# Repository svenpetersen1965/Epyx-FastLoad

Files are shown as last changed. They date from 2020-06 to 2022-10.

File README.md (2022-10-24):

# Epyx-FastLoad
A rebuild of the Epyx Fast Load cartridge for the Commodore C64 in the same format like the <a href="https://github.com/bwack/Versa64Cart">Versa64Cart<a>,
The dimensions are the same and the location of the reset switch is the same.

The software and the user manual can be obtained from this website: <a href="https://rr.pokefinder.org/wiki/Epyx_FastLoad">Epyx FastLoad (pokefinder)</a>  

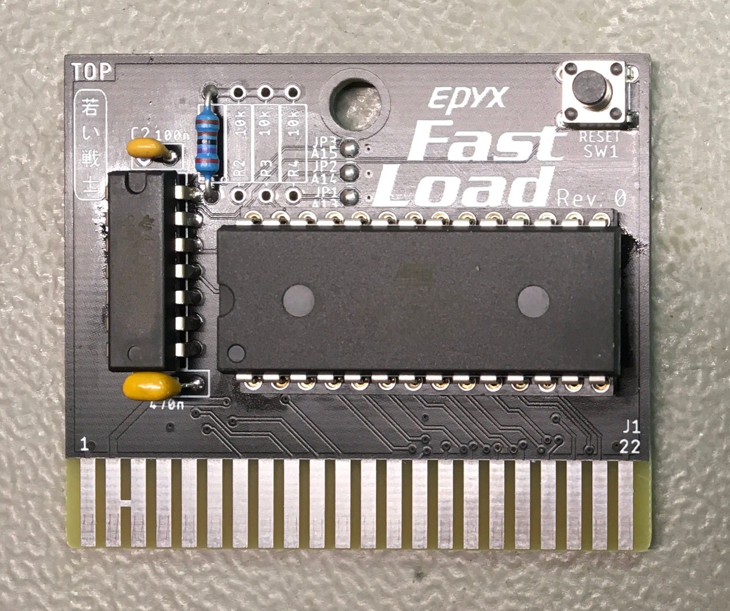
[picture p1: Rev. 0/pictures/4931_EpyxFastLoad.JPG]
Epyx FastLoad


# BOM value
The bom value is 8€, which includes the M27C512 EPROM. It was calculated with domestic prices. 

# Rev. 1
There is a jumper for selecting the software versions (there is obviously more than one version).
  
# Rev. 2
Rev. 2 is only a mechanical revision. Notches for tfw8bit.com Stumpy cartridge case were added. 

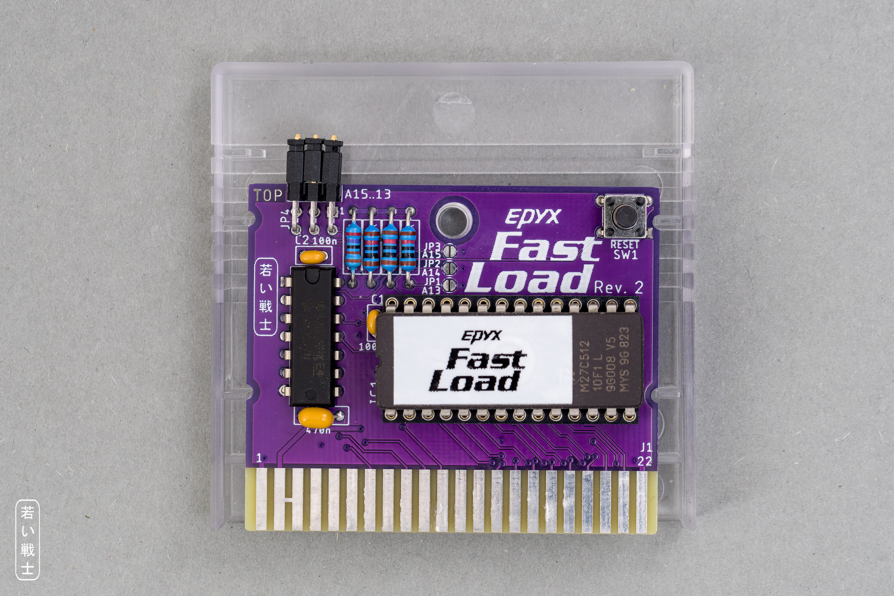
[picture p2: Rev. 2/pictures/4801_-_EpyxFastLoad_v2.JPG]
Epyx FastLoad v2

  
There is a version of the Gerber files and the eagle file without a documentation frame, since some PCB manufacturer's websites have a problem with it.

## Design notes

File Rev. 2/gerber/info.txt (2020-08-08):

      
       Board: EpyxFastLoad
       Rev.:  1
  
       Files:
       ======
  
       All Gerber files are generated in extended gerber format (RS274X)
       *.TOP        : Film top copper
       *.BOT        :  -"- bottom copper
       *.STC        :  -"- top soldermask 
       *.STS        :  -"- bottom soldermask
       *.PLC        :  -"- silk screen top
       *.PLS        :  -"- silk screen bottom
       *.DK         : Drills plated Through (Excellon)
       *.NDK        : Drills not plated Through (Excellon)
       *.OUT        : Board outline

       Board Size:
       ===========
       Length     :   58.0 mm
       Width      :   48.9 mm
       Thickness  :   1.6 mm
       Material   :   FR 4
       Copper     :   35 um
       Surface    :   HASL
       
       Remarks:
       ========
       minimum drill: 0.35mm
       minimum width: 8 mil
       minimum distance: 6 mil

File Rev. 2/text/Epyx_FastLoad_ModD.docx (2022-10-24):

Epyx FastLoad Cartridge for the C64 Rev. 2

Module Description

This is a cartridge PCB, which is suitable for the Epyx FastLoad software.

This software can be obtained here: https://rr.pokefinder.org/wiki/Epyx_FastLoad

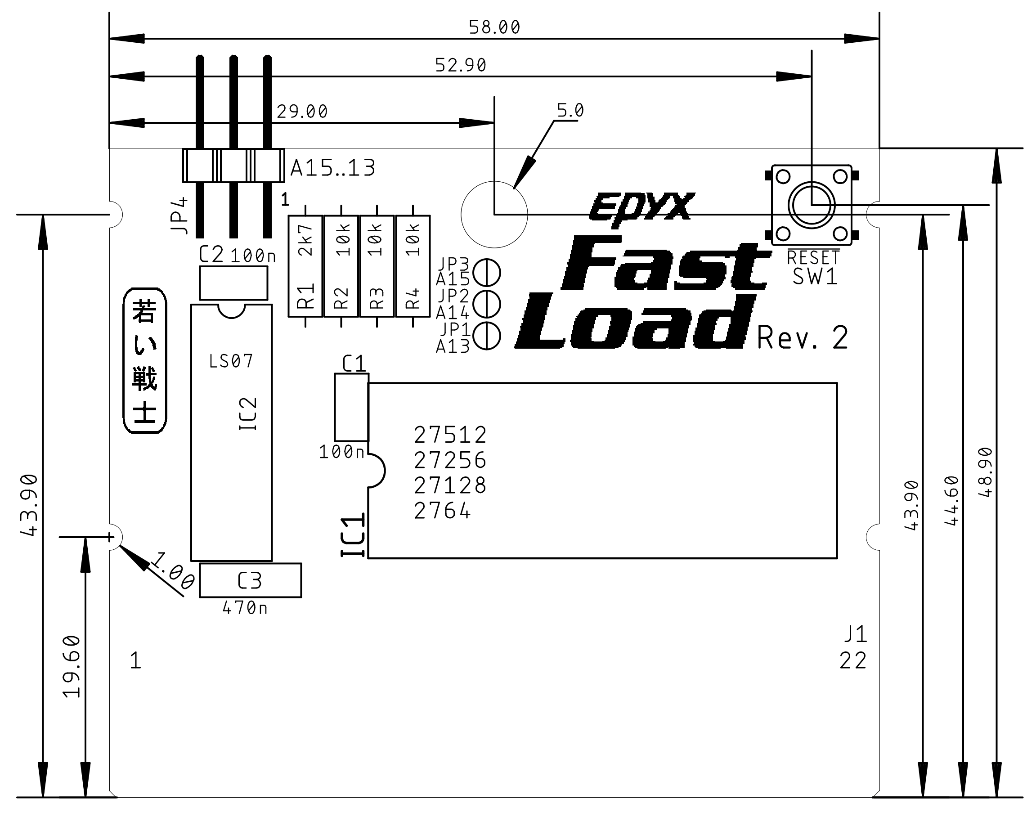
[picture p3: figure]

Figure 1: Dimensions

The circuit is based on a schematic found at the source, which was mentioned before.

A RESET button was added to this circuit and solder bridges (JP1 to JP3) for configuring the cartridge for being used with 27C64, 27C128, 27C256 and 27C512 EPROMs for a greater part availability.

EPROM | Jumper
| JP3 = A15 | JP2 = A14 | JP1 = A13
27C64 | open | open | open
27C128 | open | open | close
27C256 | open | close | close
27C512 | close | close | close

The software is programmed to the EPROM offset address 0x0000 (hex).

The dimensions are equal to the dimensions of the Versa64Cart. Notches for the Stumpy Cartridge Case were added in Rev. 2.

The memory slot can be selected with a jumper (JP4). Leave JP1..3 open and set the jumpers on the pins accordingly.

# Revision History

## Rev. 0

- Prototype, fully functional

## Rev. 1

- Board Revision
- Added JP4

## Rev. 2

- Notches added for fitting the tfw8bit.com Stumpy Cartridge Case (https://www.thefuturewas8bit.com/shop/commodore/c64/c64romcart.html)

Epyx_FastLoad_ModD.docx 24.10.2022 15:57 Drafted by Sven Petersen Page 2 of 2 Doc.-No.: 146-6-01-02

Epyx_FastLoad_ModD.docx 24.10.2022 15:57 Drafted by Sven Petersen Page 1 of 1 Doc.-No.: 000-6-00-00

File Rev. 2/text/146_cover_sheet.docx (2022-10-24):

Project Documentation

Epyx FastLoad Cartridge for the C64

Project number: 146

Revision: 2

Date: 24.10.2022

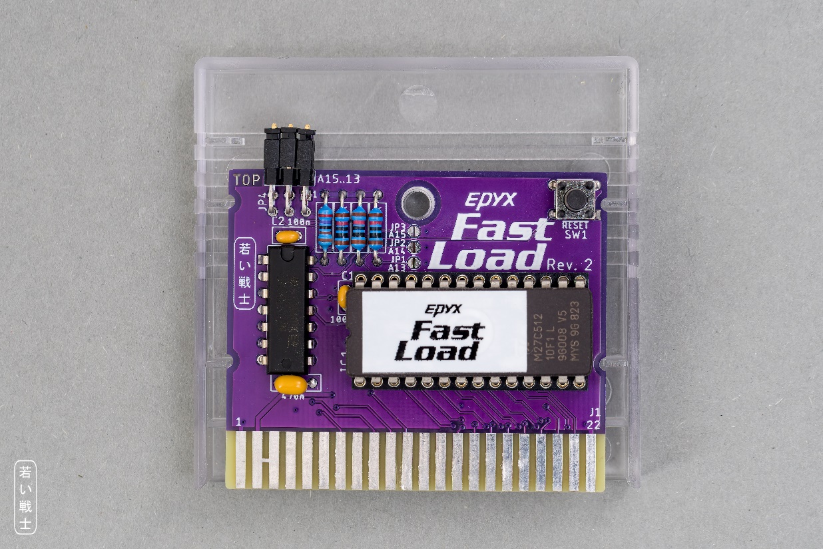
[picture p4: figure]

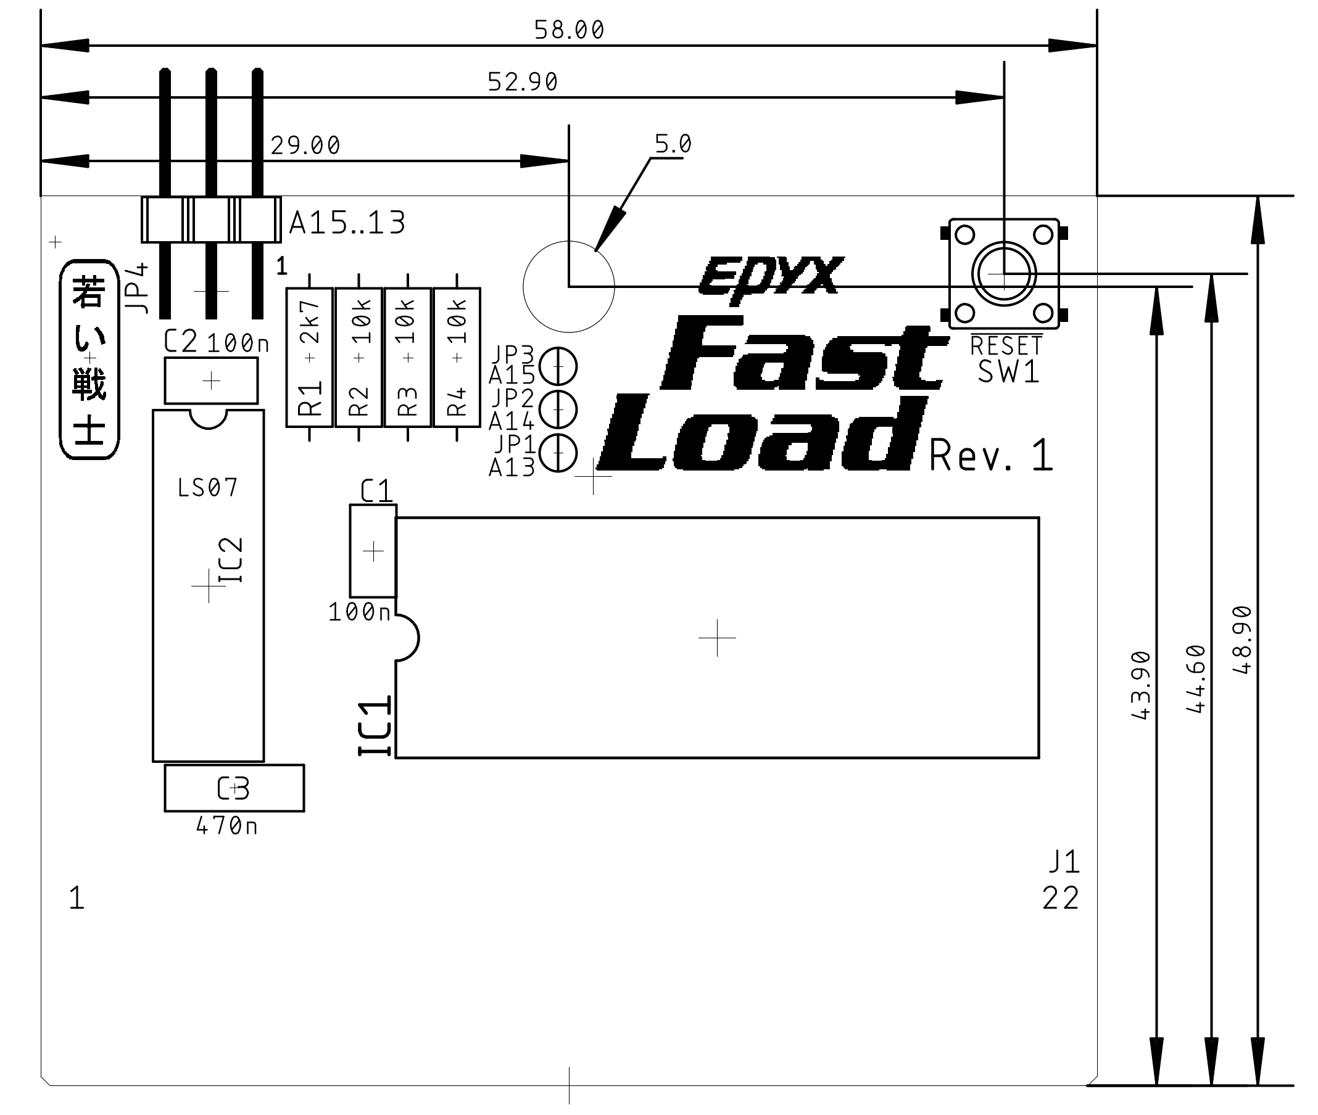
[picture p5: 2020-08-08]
Rev. 1/pictures/dimensions.png

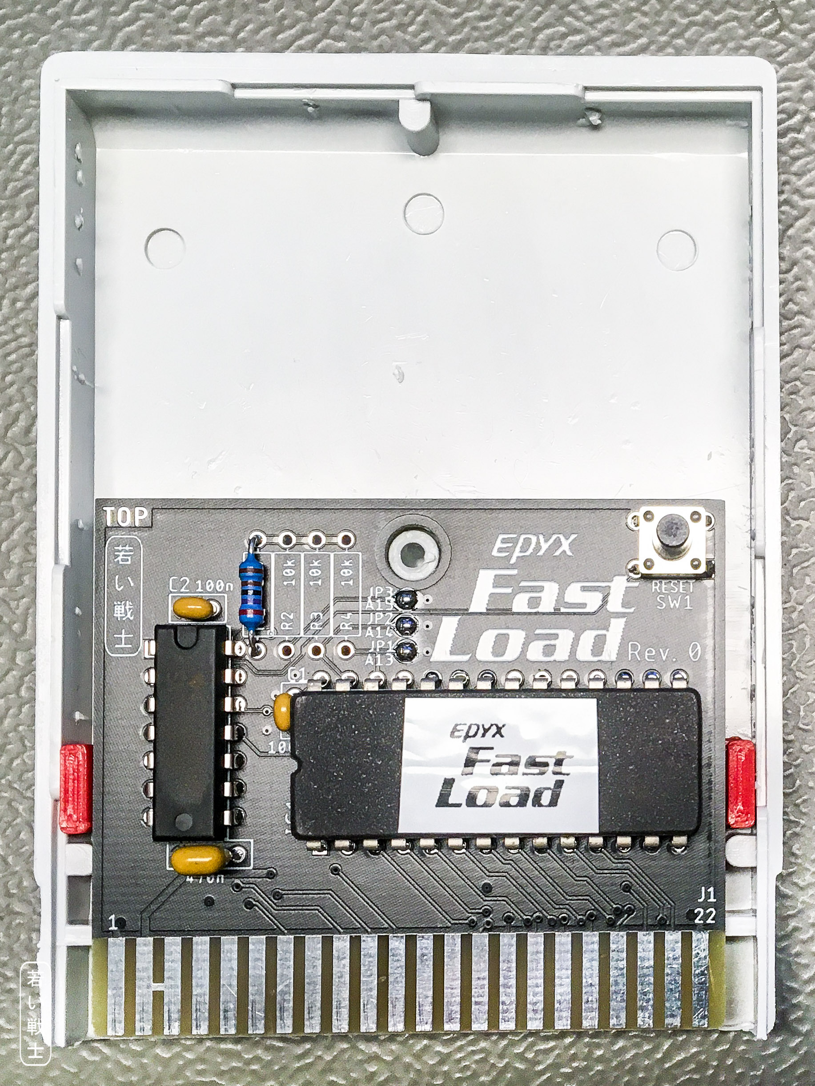
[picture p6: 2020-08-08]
Rev. 1/pictures/5124_EpyxFastLoad.JPG

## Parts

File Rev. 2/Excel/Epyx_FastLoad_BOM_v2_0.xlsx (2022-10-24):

Epxy FastLoad Cartridge Rev. 2
Bill of Material Rev. 2.0
Pos. | Qty | Value | Footprint | Ref.-No. | Comment
1 | 1 | 146-2-01-02 | 2 Layer | PCB Rev. 2 | 2 layer, Cu 35µ, HASL, 58.0mm x 48.9mm, 1.6mm FR4
2 | 3 | not an actual part | CP_OP | JP1, JP2, JP3 | Solder bridge. Configure according to doc. no. 146-6-01-**
3 | 2 | 100n | C-2,5 | C1, C2 | ceramic capacitor, pitch 2.54mm
4 | 3 | 10k | R-10 | R2, R3, R4 | resistor, metal film, 0.6W, 10% or better
5 | 1 | 27C512 | DIL28-6 | IC1 | EPROM. Alternative: 27C64, 27C128, 27C256
6 | 1 | 2k7 | R-10 | R1 | resistor, metal film, 0.6W, 10% or better
7 | 1 | 470n | C-5 | C3 | ceramic capacitor, pitch 5.08mm
8 | 1 | JTP-1130 | JTP-1130 | SW1 | tact switch, 6x6mm,
9 | 1 | SN74LS07N | DIL-14 | IC2 | e.g. Texas Instruments SN74LS07N
10 | 1 | Pin header, 2x3, 90° | 2x3, 90° | JP4 | Optional Pinherader
11 | 3 | Jumper 2.54mm |  | (JP4) | Optional Jumper
 |  | Rev. History
 |  | Rev. 1
Pos. | 1 | Board revision
Pos. | 10 | new
Pos. | 11 | new
 |  | Rev. 2
Pos. | 1 | Board revision

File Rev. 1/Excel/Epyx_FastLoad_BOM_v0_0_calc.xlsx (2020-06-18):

Epxy FastLoad Cartridge Rev. 0
Bill of Material Rev. 0.0
Pos. | Qty | Value | €/ea | € | Comment
1 | 1 | 146-2-01-00 | 1.00 € | 1.00 € | 2 layer, Cu 35µ, HASL, 58.0mm x 48.9mm, 1.6mm FR4
2 | 3 | not an actual part | 0.00 € | 0.00 € | Solder bridge. Configure according to doc. no. 146-6-01-**
3 | 2 | 100n | 0.20 € | 0.40 € | ceramic capacitor, pitch 2.54mm
4 | 3 | 10k | 0.05 € | 0.15 € | resistor, metal film, 0.6W, 10% or better
5 | 1 | 27C512 | 5.40 € | 5.40 € | EPROM. Alternative: 27C64, 27C128, 27C256
6 | 1 | 2k7 | 0.05 € | 0.05 € | resistor, metal film, 0.6W, 10% or better
7 | 1 | 470n | 0.19 € | 0.19 € | ceramic capacitor, pitch 5.08mm
8 | 1 | JTP-1130 | 0.15 € | 0.15 € | tact switch, 6x6mm,
9 | 1 | SN74LS07N | 0.66 € | 0.66 € | e.g. Texas Instruments SN74LS07N
10 |  |  | Total | 8.00 €

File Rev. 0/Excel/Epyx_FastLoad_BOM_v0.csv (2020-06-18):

Qty | Value | Device | Package | Parts | Description
3 |  | OPEN | CP_OP | JP1, JP2, JP3 | open Cutpad
2 | 100n | CAP01 | C-2,5 | C1, C2
3 | 10k | RES04 | R-10 | R2, R3, R4
1 | 27C512-DIP28 | M27C512-DIP28 | DIL28-6 | IC1
1 | 2k7 | RES04 | R-10 | R1
1 | 470n | CAP02 | C-5 | C3
1 | C64-EXPANSION-PORT | C64-EXPANSIONPNARROW | EXPANSIO_SQ | J1
1 | JTP-1130 | JTP-1130 | JTP-1130 | SW1
1 | SN74LS07N | 7407N | DIL-14 | IC2

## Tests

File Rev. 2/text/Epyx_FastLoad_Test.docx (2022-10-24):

Epyx FastLoad Cartridge for the C64 Rev. 2

Testing

# Tests

The tests were carried out with the prototype Rev. 0 and Rev. 2. The software was stored on an AT27C256R (Atmel) and an ST M27C512 EPROM.

The Epxy FastLoad cartridge was tested with:

- ASSY 250469
- ASSY 250425
- ASSY 250407
- Ultimate 64 Elite (Firmware v1.26)

The Ultimate 64 Elite did not boot. This is a known issue. This was not tested with Rev. 2 again.

All original C64, that were tested, booted without a problem. The FDD 1541 could be accessed.

Rev. 2 was tested on ASSY250469 (the circuitry of the cartridge did not change).

- Several times switched on
- Several times reset button

The software always loaded, the menu could be loaded with the £ key. Some menu functions were tested. The directory, some 1541 commands worked and programs could be loaded.

# Conclusion

Rev. 2 is fully functional.

Epyx_FastLoad_Test.docx 24.10.2022 16:08 Drafted by Sven Petersen Page 2 of 2 Doc.-No.: 000-6-00-00

Epyx_FastLoad_Test.docx 24.10.2022 16:08 Drafted by Sven Petersen Page 1 of 1 Doc.-No.: 146-6-02-02

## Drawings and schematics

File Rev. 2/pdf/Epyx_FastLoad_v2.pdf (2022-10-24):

# Project Documentation

## Epyx FastLoad Cartridge for the C64

## Project number: 146

## Revision: 2

## Date: 24.10.2022

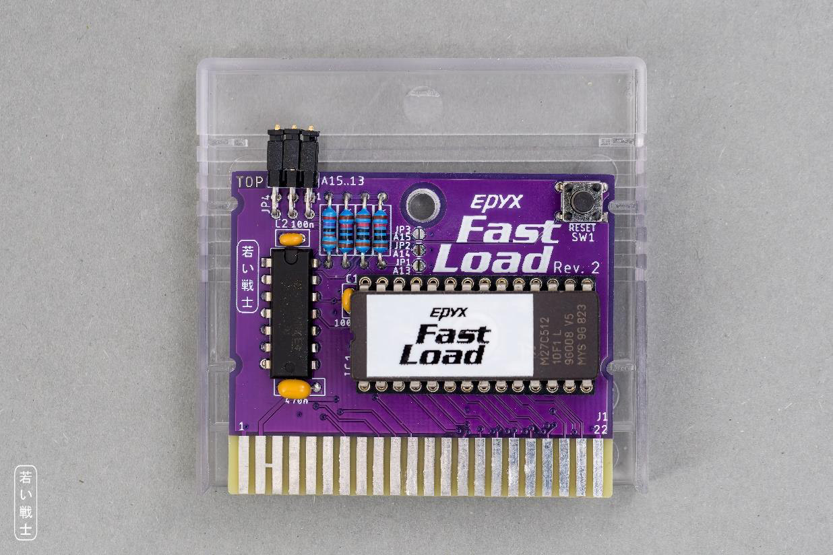
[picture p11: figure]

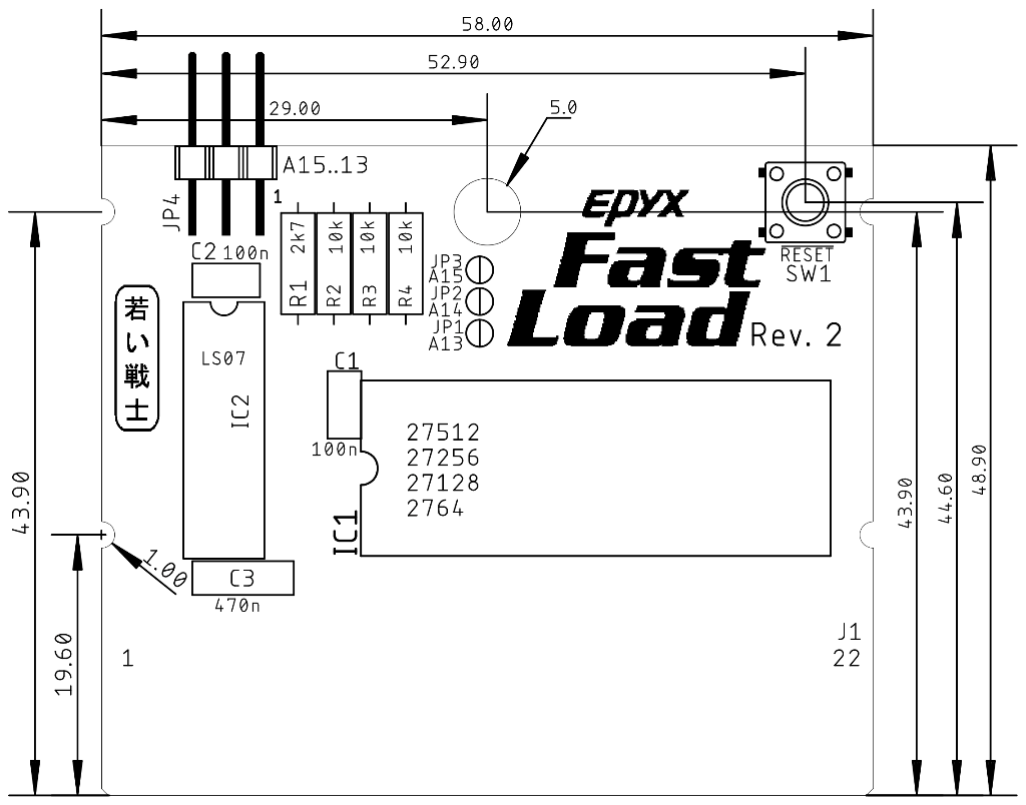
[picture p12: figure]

Epyx_FastLoad_ModD.docx | | 24.10.2022 15:57
Drafted by Sven Petersen | Page 1 of 2 | Doc.-No.: 146-6-01-02

### Epyx FastLoad Cartridge for the C64 Rev. 2

### Module Description

This is a cartridge PCB, which is suitable for the Epyx FastLoad software.

This software can be obtained here: https://rr.pokefinder.org/wiki/Epyx_FastLoad

Figure 1: Dimensions

The circuit is based on a schematic found at the source, which was mentioned before.

A RESET button was added to this circuit and solder bridges (JP1 to JP3) for configuring the cartridge for being used with 27C64, 27C128, 27C256 and 27C512 EPROMs for a greater part availability.

EPROM

Jumper
JP3 = A15 | JP2 = A14 | JP1 = A13
27C64 | open | open | open
27C128 | open | open | close
27C256 | open | close | close
27C512 | close | close | close

The software is programmed to the EPROM offset address 0x0000 (hex).

The dimensions are equal to the dimensions of the Versa64Cart. Notches for the Stumpy Cartridge Case were added in Rev. 2.

The memory slot can be selected with a jumper (JP4). Leave JP1..3 open and set the jumpers on the pins accordingly.

Epyx_FastLoad_ModD.docx | | 24.10.2022 15:57
Drafted by Sven Petersen | Page 2 of 2 | Doc.-No.: 146-6-01-02

## Revision History

### Rev. 0

- Prototype, fully functional

### Rev. 1

- Board Revision
- Added JP4

### Rev. 2

- Notches added for fitting the tfw8bit.com Stumpy Cartridge Case (https://www.thefuturewas8bit.com/shop/commodore/c64/c64romcart.html)

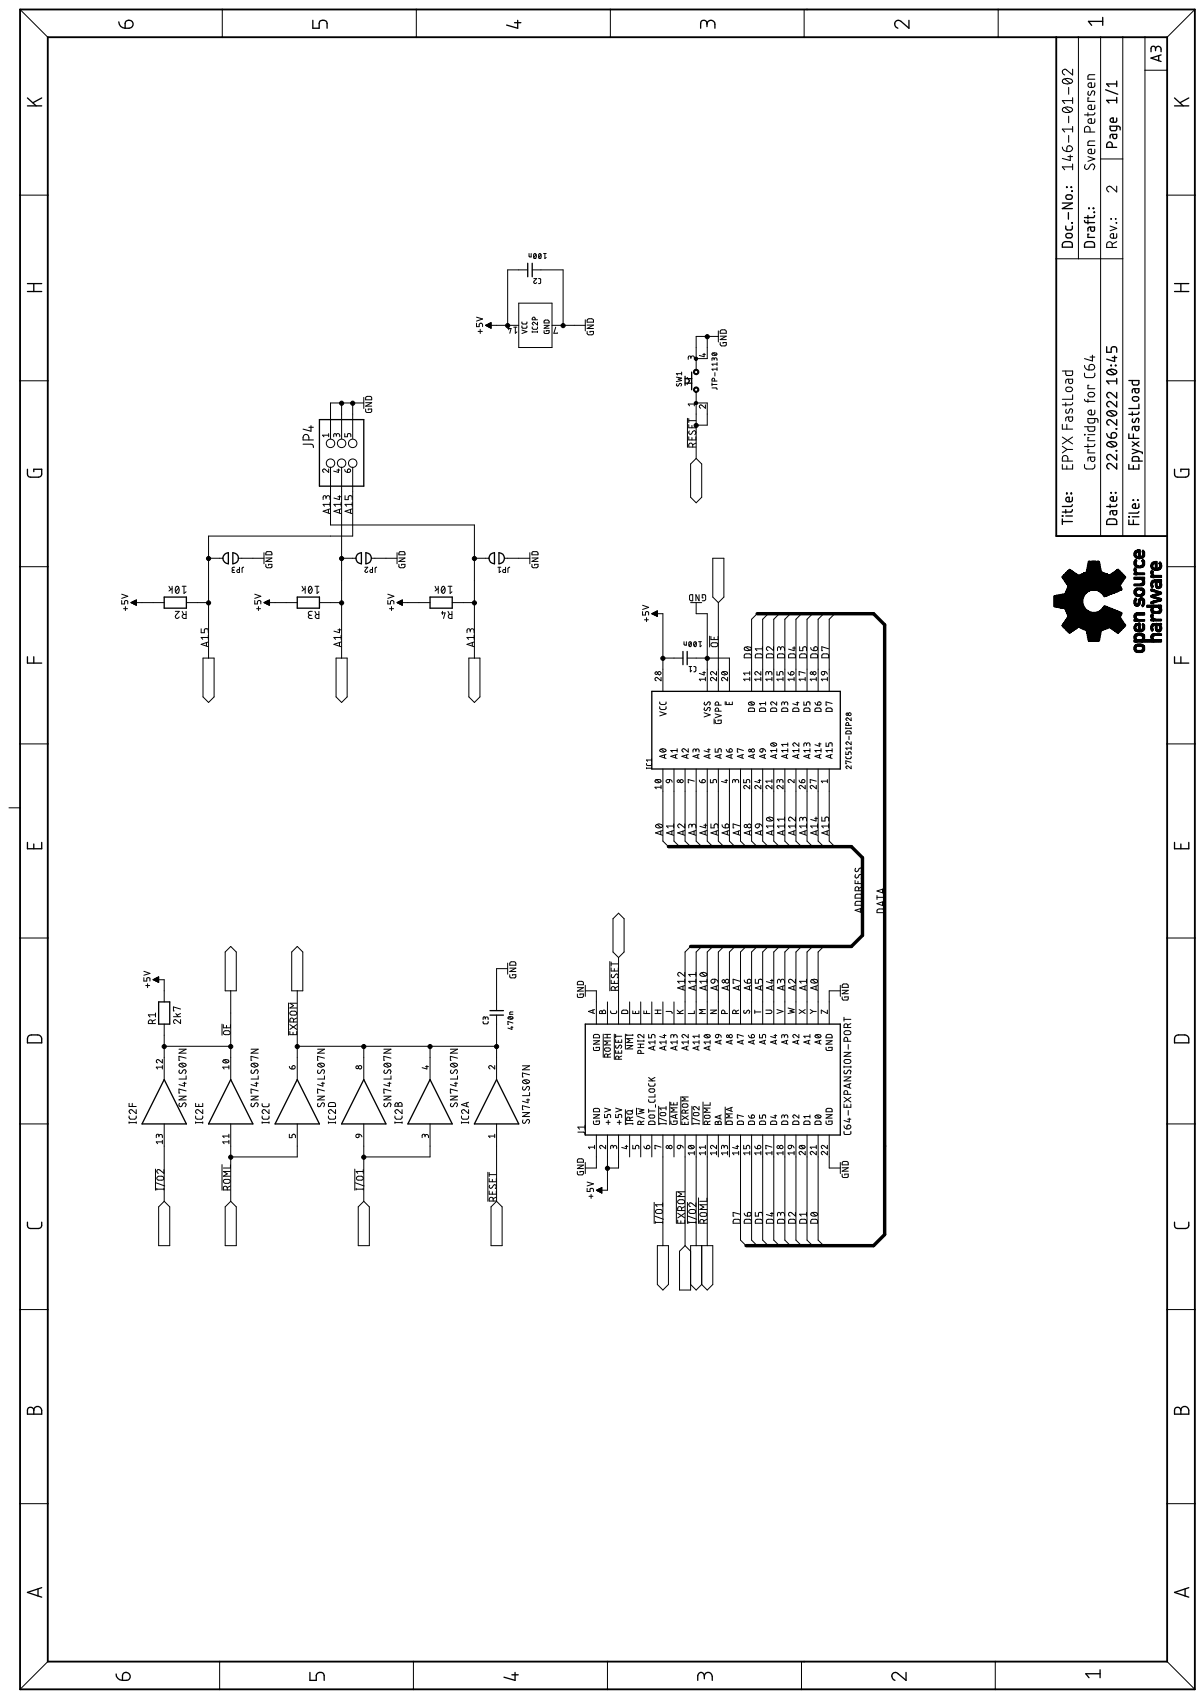
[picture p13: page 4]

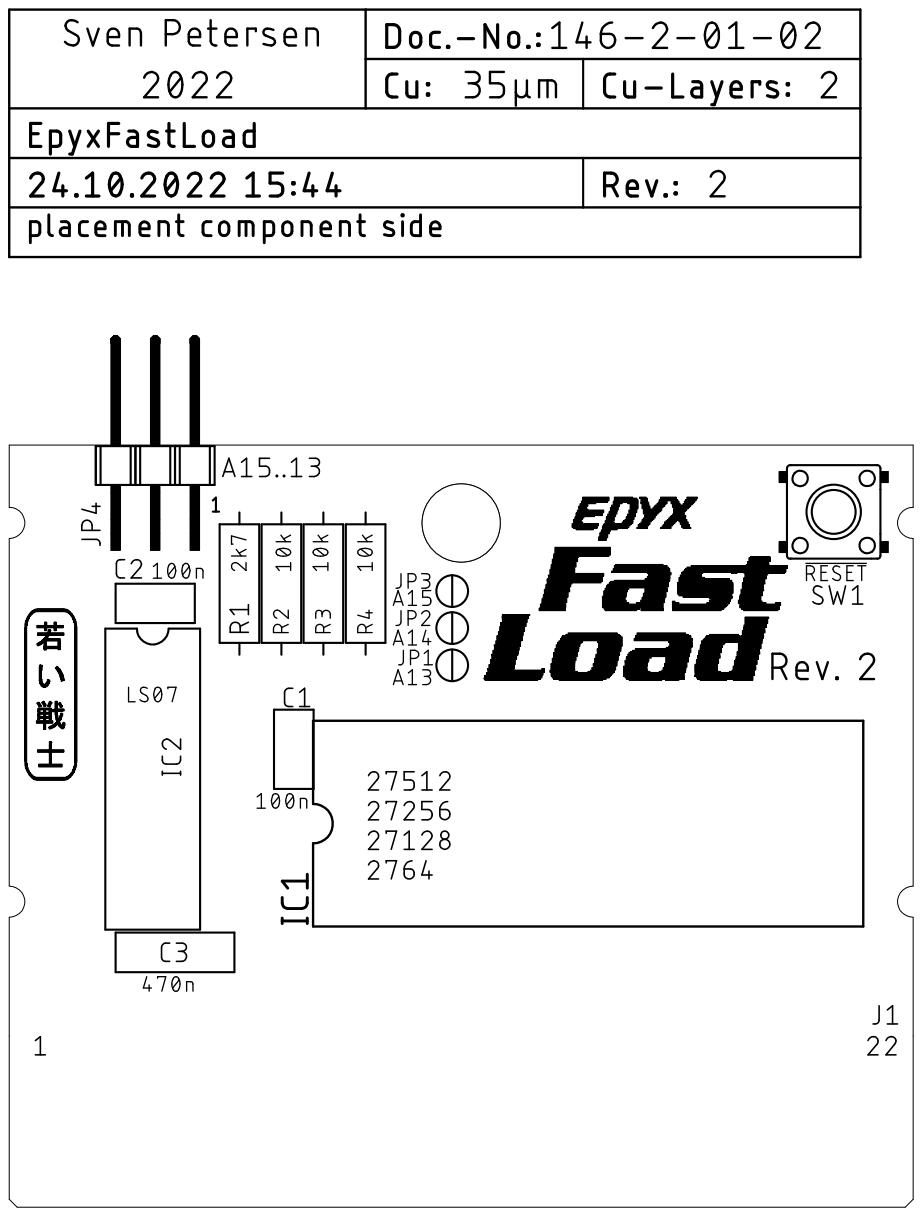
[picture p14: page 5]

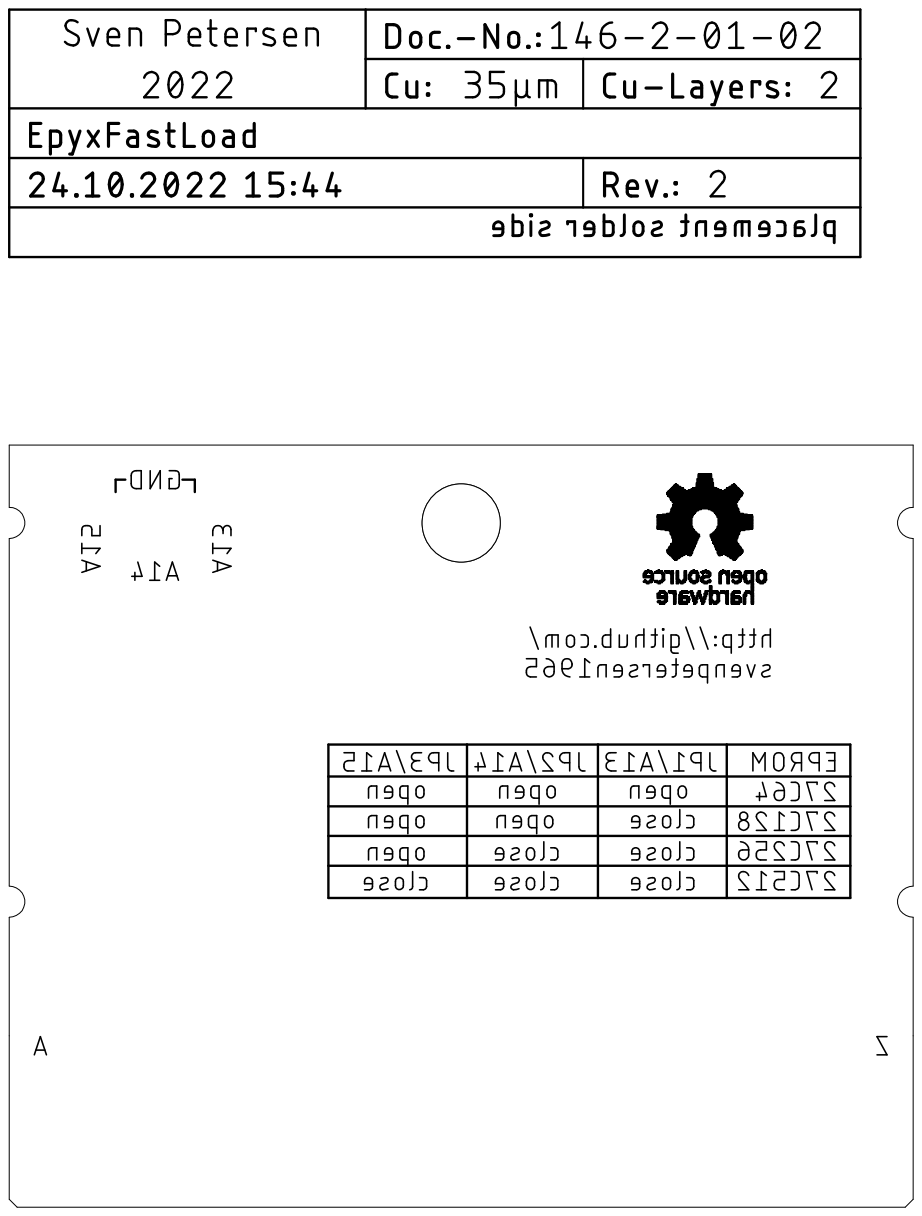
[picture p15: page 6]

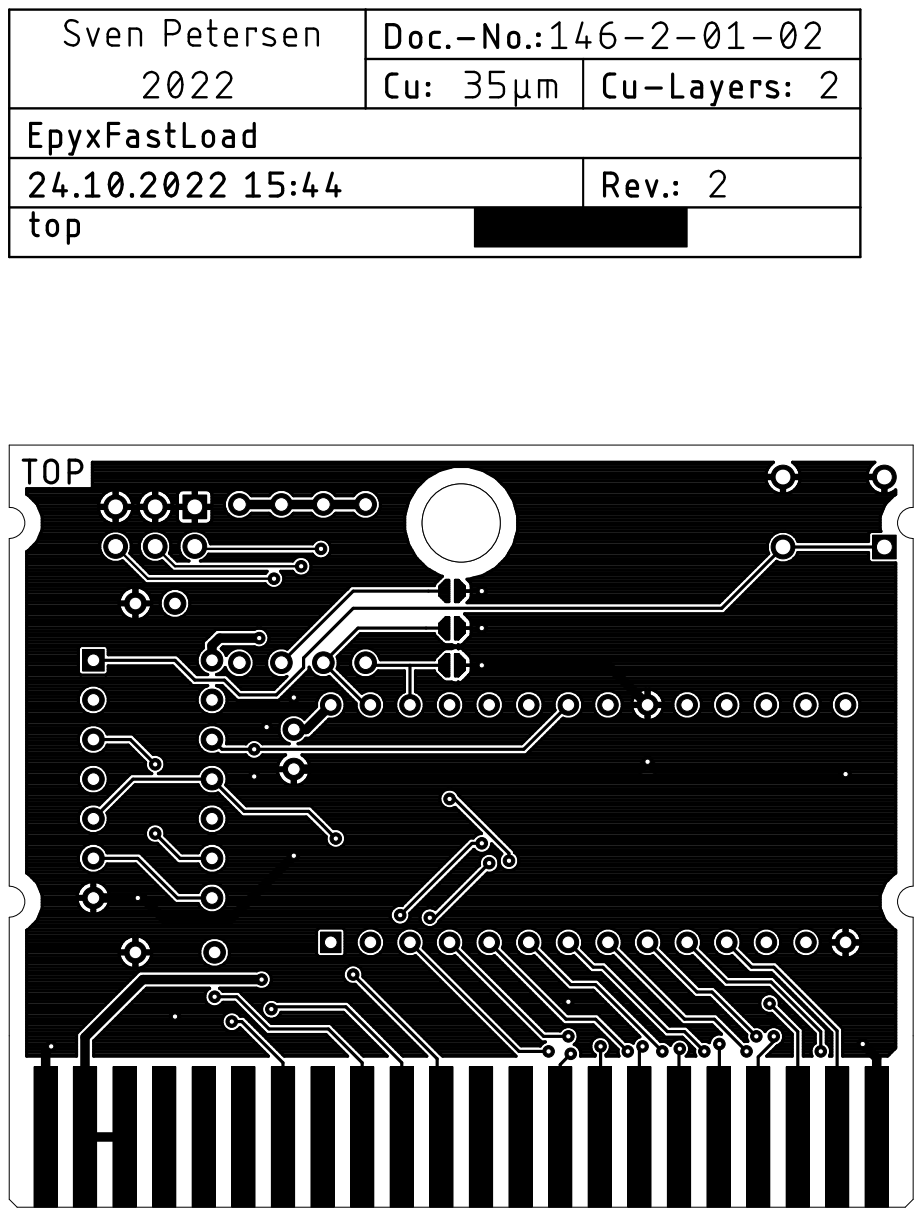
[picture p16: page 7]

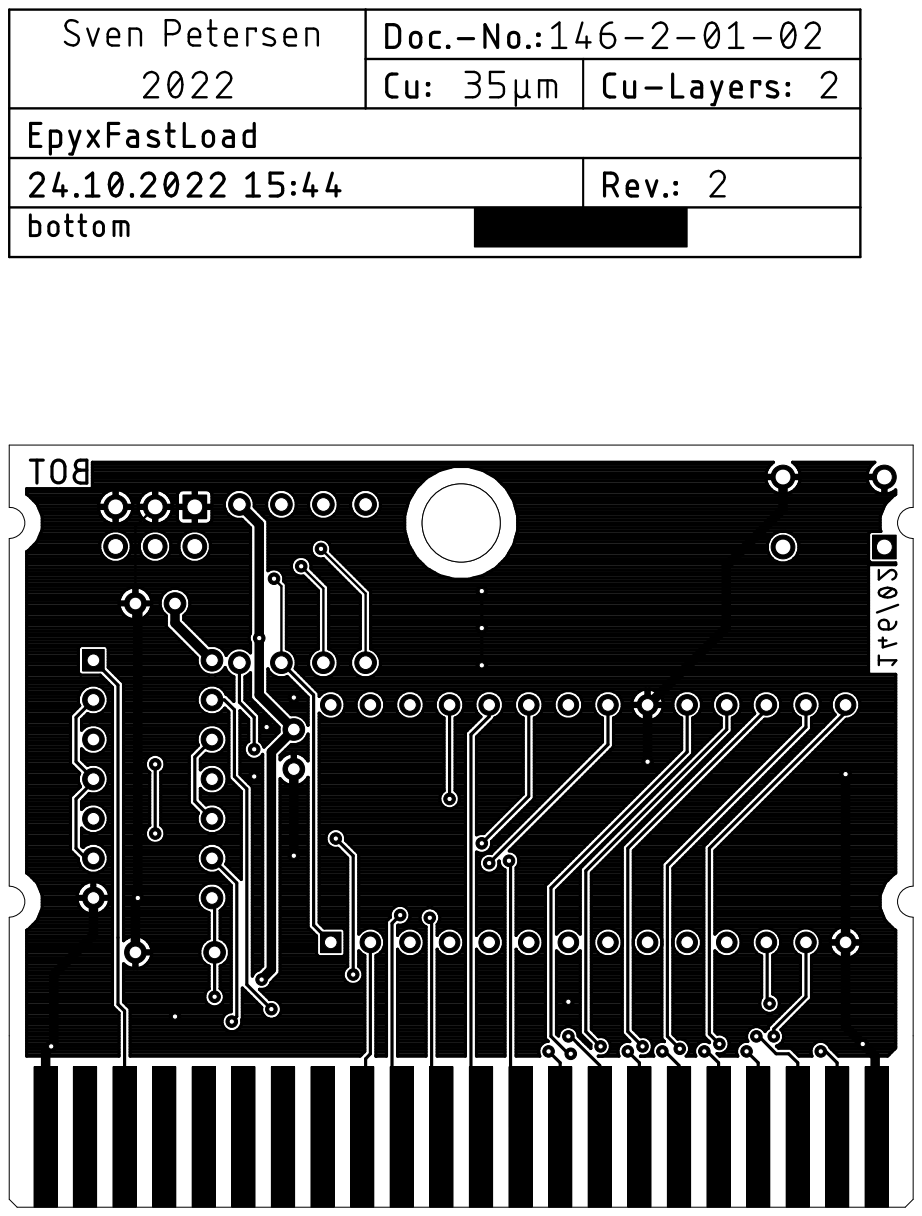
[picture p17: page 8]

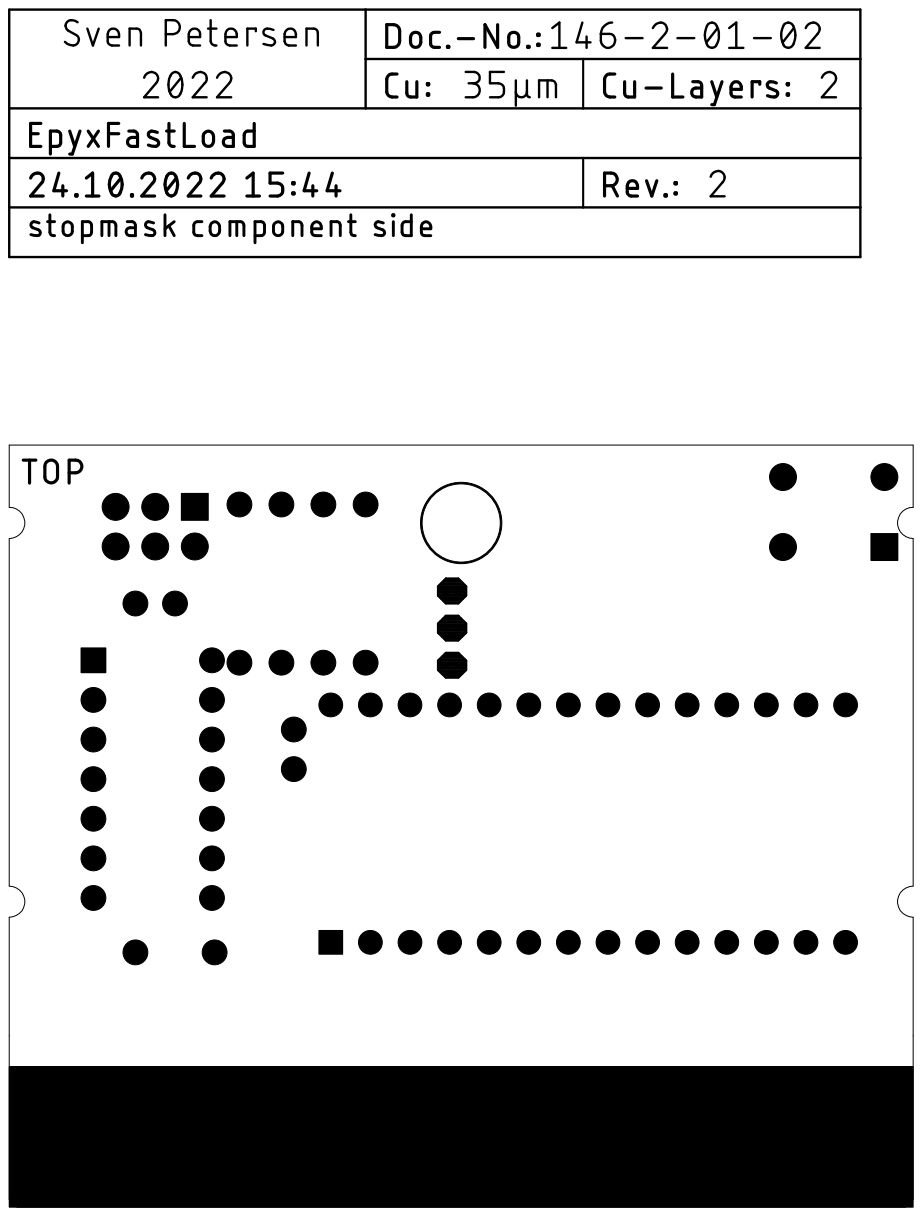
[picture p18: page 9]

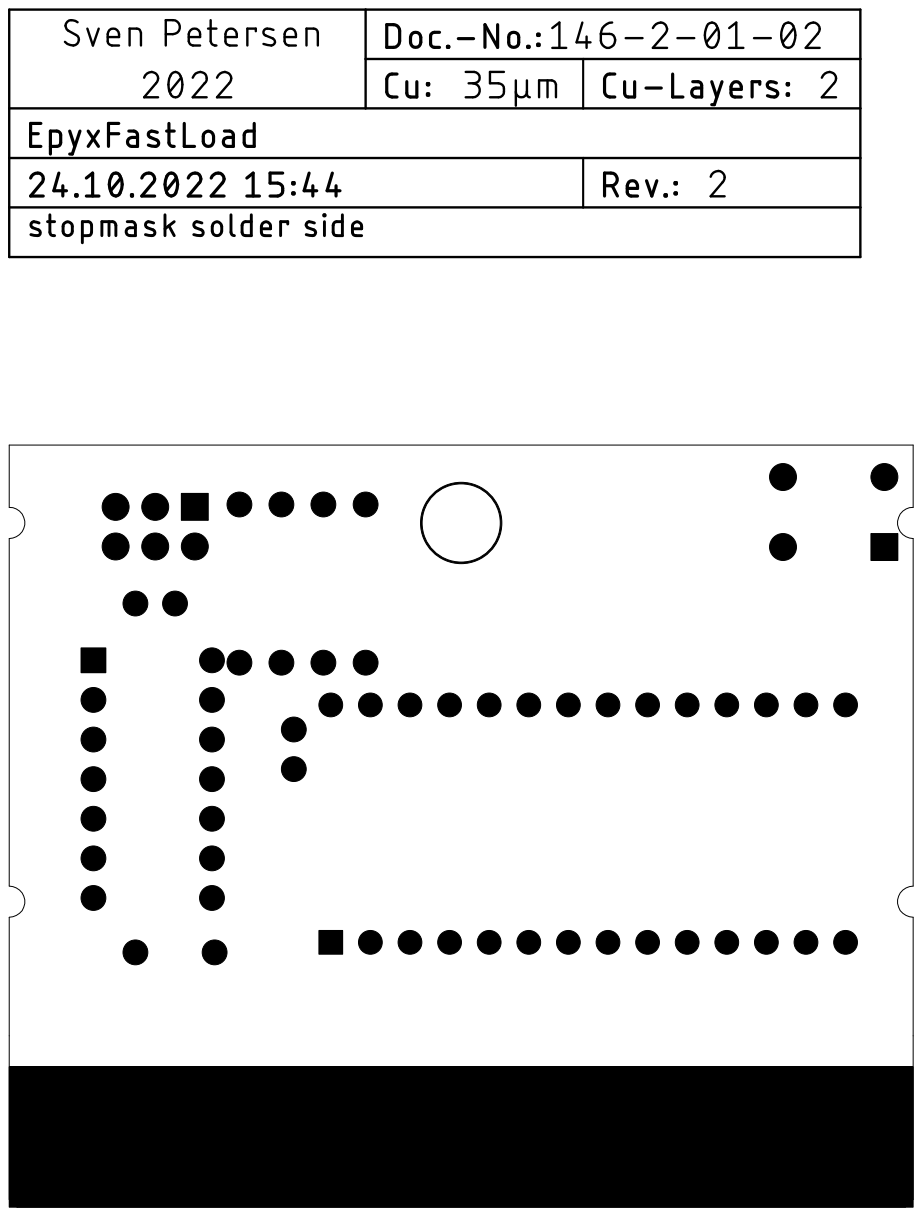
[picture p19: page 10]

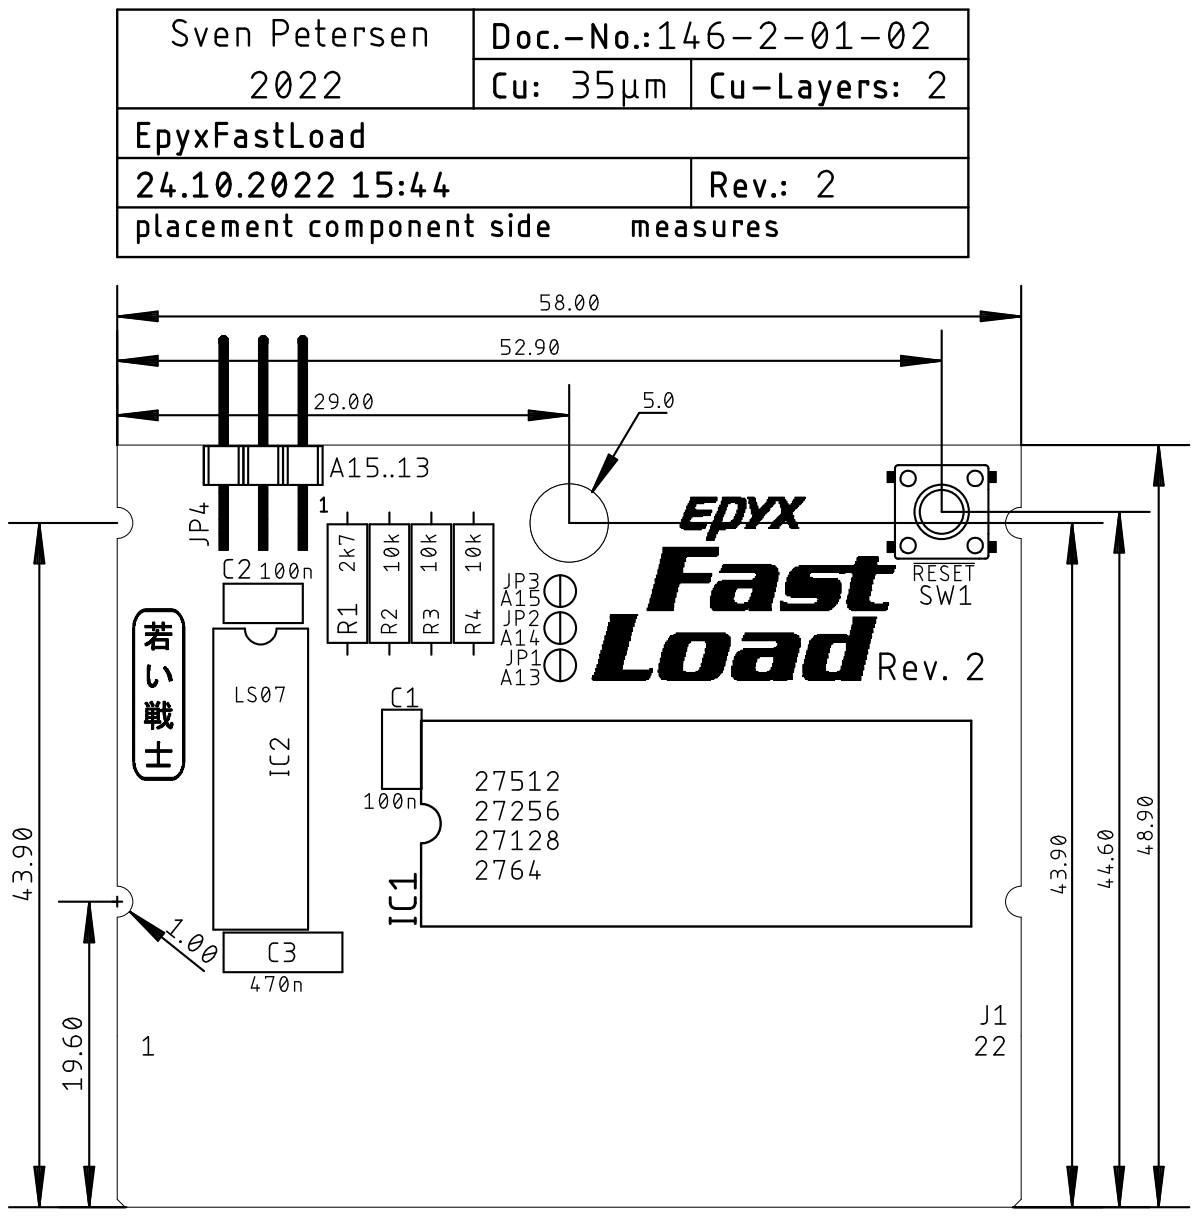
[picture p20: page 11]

Epyx_FastLoad_Test.docx | | 24.10.2022 16:08
Drafted by Sven Petersen | Page 1 of 1 | Doc.-No.: 146-6-02-02

### Epyx FastLoad Cartridge for the C64 Rev. 2

### Testing

## Tests

The tests were carried out with the prototype Rev. 0 and Rev. 2. The software was stored on an AT27C256R (Atmel) and an ST M27C512 EPROM.

The Epxy FastLoad cartridge was tested with:

- ASSY 250469
- ASSY 250425
- ASSY 250407
- Ultimate 64 Elite (Firmware v1.26)

The Ultimate 64 Elite did not boot. This is a known issue. This was not tested with Rev. 2 again.

All original C64, that were tested, booted without a problem. The FDD 1541 could be accessed.

Rev. 2 was tested on ASSY250469 (the circuitry of the cartridge did not change).

- Several times switched on
- Several times reset button

The software always loaded, the menu could be loaded with the £ key. Some menu functions were tested. The directory, some 1541 commands worked and programs could be loaded.

## Conclusion

Rev. 2 is fully functional.

Pos. Qty Value Footprint Ref.-No. Comment

1 1 146-2-01-02 2 Layer PCB Rev. 2 2 layer, Cu 35µ, HASL, 58.0mm x 48.9mm, 1.6mm FR4

2 3 not an actual part CP_OP JP1, JP2, JP3 Solder bridge. Configure according to doc. no. 146-6-01-

**

3 2 100n C-2,5 C1, C2 ceramic capacitor, pitch 2.54mm

4 3 10k R-10 R2, R3, R4 resistor, metal film, 0.6W, 10% or better

5 1 27C512 DIL28-6 IC1 EPROM. Alternative: 27C64, 27C128, 27C256

6 1 2k7 R-10 R1 resistor, metal film, 0.6W, 10% or better

7 1 470n C-5 C3 ceramic capacitor, pitch 5.08mm

8 1 JTP-1130 JTP-1130 SW1 tact switch, 6x6mm,

9 1 SN74LS07N DIL-14 IC2 e.g. Texas Instruments SN74LS07N

10 1 Pin header, 2x3, 90° 2x3, 90° JP4 Optional Pinherader
11 3 Jumper 2.54mm (JP4) Optional Jumper

Rev. History

Rev. 1

Pos. 1 Board revision

Pos. 10 new

Pos. 11 new

Rev. 2

Pos. 1 Board revision

## Epxy FastLoad Cartridge Rev. 2

## Bill of Material Rev. 2.0

Epyx_FastLoad_BOM_v2_0.xlsx

Drafted by Sven Petersen Page 1 of 1

24.10.2022 16:12
Doc.No.: 146-5-01-02.0

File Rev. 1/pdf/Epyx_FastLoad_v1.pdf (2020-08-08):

# Project Documentation

## Epyx FastLoad Cartridge for the C64

## Project number: 146

## Revision: 1

## Date: 08.08.2020

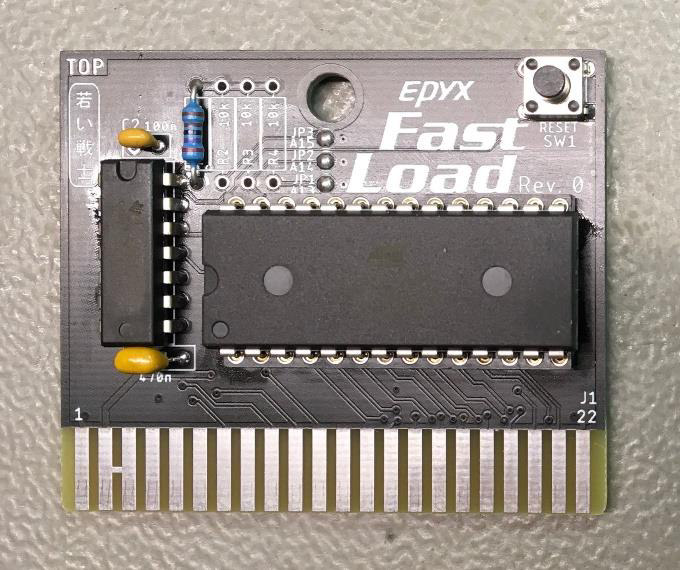
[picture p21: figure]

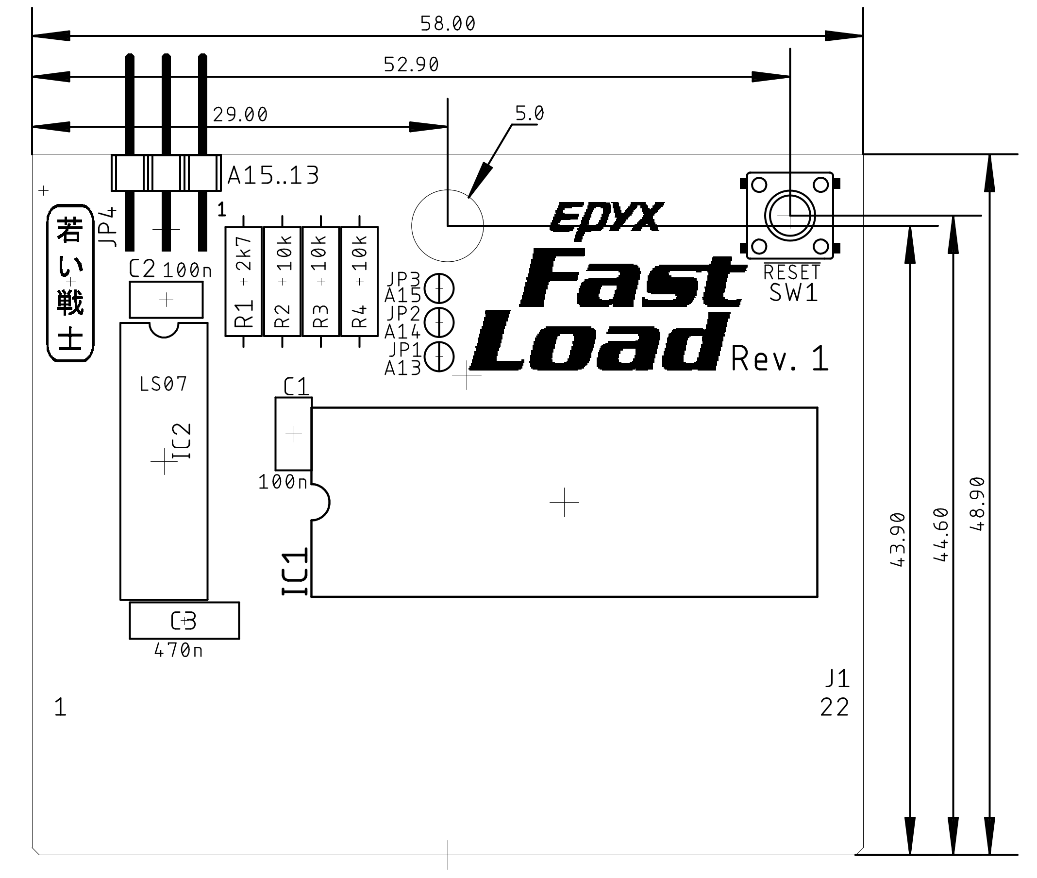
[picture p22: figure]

Epyx_FastLoad_ModD.docx | | 08.08.2020 21:34
Drafted by Sven Petersen | Page 1 of 2 | Doc.-No.: 146-6-01-01

### Epyx FastLoad Cartridge for the C64 Rev. 1

### Module Description

This is a cartridge PCB, which is suitable for the Epyx FastLoad software.

This software can be obtained here: https://rr.pokefinder.org/wiki/Epyx_FastLoad

Figure 1: Dimensions

The circuit is based on a schematic found at the source, which was mentioned before.

A RESET button was added to this circuit and solder bridges (JP1 to JP3) for configuring the cartridge for being used with 27C64, 27C128, 27C256 and 27C512 EPROMs for a greater part availability.

EPROM

Jumper
JP3 = A15 | JP2 = A14 | JP1 = A13
27C64 | open | open | open
27C128 | open | open | close
27C256 | open | close | close
27C512 | close | close | close

The software is programmed to the EPROM offset address 0x0000 (hex).

The dimensions are equal to the dimensions of the Versa64Cart.

The memory slot can be selected with a jumper (JP4). Leave JP1..3 open and set the jumpers on the pins accordingly.

Epyx_FastLoad_ModD.docx | | 08.08.2020 21:34
Drafted by Sven Petersen | Page 2 of 2 | Doc.-No.: 146-6-01-01

## Revision History

### Rev. 0

- Prototype, fully functional

### Rev. 1

- Board Revision
- Added JP4









Epyx_FastLoad_Test.docx | | 08.08.2020 21:14
Drafted by Sven Petersen | Page 1 of 1 | Doc.-No.: 146-6-02-01

### Epyx FastLoad Cartridge for the C64 Rev. 1

### Testing

## Tests

The tests were carried out with the prototype Rev. 0. The software was stored on an AT27C256R (Atmel) EPROM.

The Epxy FastLoad cartridge was tested with:

- ASSY 250469
- ASSY 250425
- ASSY 250407
- Ultimate 64 Elite (Firmware v1.26)

The Ultimate 64 Elite did not boot. This is a known issue.

All original C64, that were tested, booted without a problem. The FDD 1541 could be accessed.

## Conclusion

Rev. 0 is fully functional.

Pos. Qty Value Footprint Ref.-No. Comment

1 1 146-2-01-01 2 Layer PCB Rev. 1 2 layer, Cu 35µ, HASL, 58.0mm x 48.9mm, 1.6mm FR4

2 3 not an actual part CP_OP JP1, JP2, JP3 Solder bridge. Configure according to doc. no. 146-6-01-

**

3 2 100n C-2,5 C1, C2 ceramic capacitor, pitch 2.54mm

4 3 10k R-10 R2, R3, R4 resistor, metal film, 0.6W, 10% or better

5 1 27C512 DIL28-6 IC1 EPROM. Alternative: 27C64, 27C128, 27C256

6 1 2k7 R-10 R1 resistor, metal film, 0.6W, 10% or better

7 1 470n C-5 C3 ceramic capacitor, pitch 5.08mm

8 1 JTP-1130 JTP-1130 SW1 tact switch, 6x6mm,

9 1 SN74LS07N DIL-14 IC2 e.g. Texas Instruments SN74LS07N

10 1 Pin header, 2x3, 90° 2x3, 90° JP4 Optional Pinherader
11 3 Jumper 2.54mm (JP4) Optional Jumper

Rev. History

Rev. 1

Pos. 1 Board revision

Pos. 10 new

Pos. 11 new

## Epxy FastLoad Cartridge Rev. 1

## Bill of Material Rev. 1.0

Epyx_FastLoad_BOM_v1_0.xlsx

Drafted by Sven Petersen Page 1 of 1

08.08.2020 21:38
Doc.No.: 146-5-01-01.0

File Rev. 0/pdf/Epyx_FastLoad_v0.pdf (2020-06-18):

# Project Documentation

## Epyx FastLoad Cartridge for the C64

## Project number: 146

## Revision: 0

## Date: 12.05.2020



Epyx_FastLoad_ModD.docx | | 12.05.2020 12:00
Drafted by Sven Petersen | Page 1 of 1 | Doc.-No.: 146-6-01-00

### Epyx FastLoad Cartridge for the C64 Rev. 0

### Module Description

This is a cartridge PCB, which is suitable for the Epyx FastLoad software.

This software can be obtained here: https://rr.pokefinder.org/wiki/Epyx_FastLoad

Figure 1: Dimensions

The circuit is based on a schematic found at the source, which was mentioned before.

A RESET button was added to this circuit and solder bridges (JP1 to JP3) for configuring the cartridge for being used with 27C64, 27C128, 27C256 and 27C512 EPROMs for a greater part availability.

EPROM

Jumper
JP3 = A15 | JP2 = A14 | JP1 = A13
27C64 | open | open | open
27C128 | open | open | close
27C256 | open | close | close
27C512 | close | close | close

The software is programmed to the EPROM offset address 0x0000 (hex).

The dimensions are equal to the dimensions of the Versa64Cart.










Pos. Qty Value Footprint Ref.-No. Comment

1 1 146-2-01-00 2 Layer PCB Rev. 0 2 layer, Cu 35µ, HASL, 58.0mm x 48.9mm, 1.6mm FR4

2 3 not an actual part CP_OP JP1, JP2, JP3 Solder bridge. Configure according to doc. no. 146-6-01-

**

3 2 100n C-2,5 C1, C2 ceramic capacitor, pitch 2.54mm

4 3 10k R-10 R2, R3, R4 resistor, metal film, 0.6W, 10% or better

5 1 27C512 DIL28-6 IC1 EPROM. Alternative: 27C64, 27C128, 27C256

6 1 2k7 R-10 R1 resistor, metal film, 0.6W, 10% or better

7 1 470n C-5 C3 ceramic capacitor, pitch 5.08mm

8 1 JTP-1130 JTP-1130 SW1 tact switch, 6x6mm,

9 1 SN74LS07N DIL-14 IC2 e.g. Texas Instruments SN74LS07N

## Epxy FastLoad Cartridge Rev. 0

## Bill of Material Rev. 0.0

Epyx_FastLoad_BOM_v0_0.xlsx

Drafted by Sven Petersen Page 1 of 1

12.05.2020 12:13
Doc.No.: 146-5-01-00.0

Epyx_FastLoad_Test.docx | | 18.06.2020 12:14
Drafted by Sven Petersen | Page 1 of 1 | Doc.-No.: 146-6-02-00

### Epyx FastLoad Cartridge for the C64 Rev. 0

### Testing

## Tests

The tests were carried out with the prototype Rev. 0. The software was stored on an AT27C256R (Atmel) EPROM.

The Epxy FastLoad cartridge was tested with:

- ASSY 250469
- ASSY 250425
- ASSY 250400
- Ultimate 64 Elite (Firmware v1.26)

The Ultimate 64 Elite did not boot. This is a known issue.

All original C64, that were tested, booted without a problem. The FDD 1541 could be accessed.

## Conclusion

Rev. 0 is fully functional.

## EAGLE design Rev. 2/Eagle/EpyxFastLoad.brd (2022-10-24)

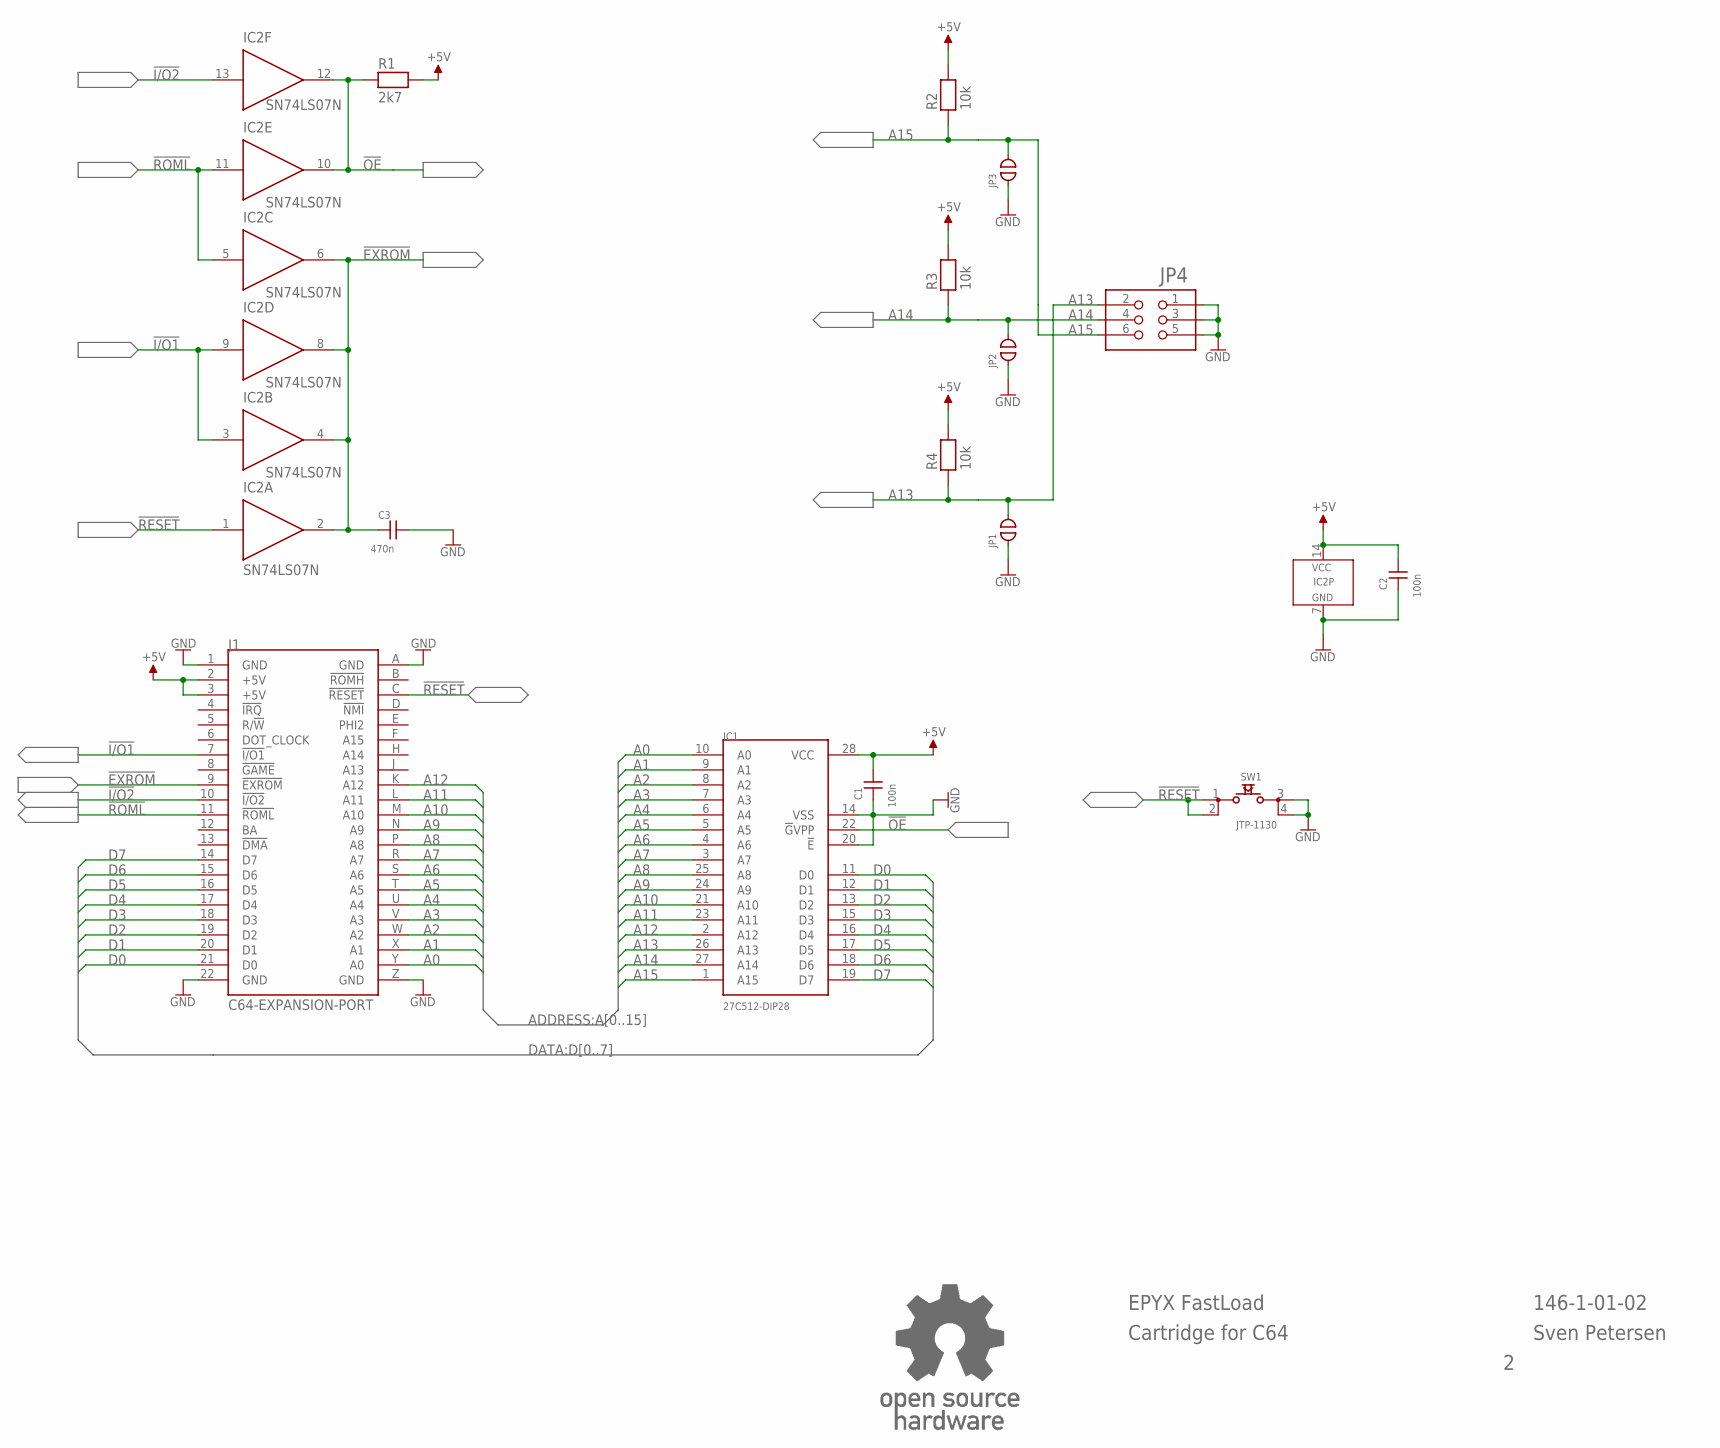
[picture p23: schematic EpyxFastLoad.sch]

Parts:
C1, C2: 100n; C-2,5
C3: 470n; C-5
IC1: 27C512-DIP28; DIL28-6
IC2: SN74LS07N; DIL-14
J1: C64-EXPANSION-PORT; EXPANSIO_SQ
JP1, JP2, JP3: OPEN; CP_OP
JP4: PINHD-2X390°; 2X03_90_SERIES_088
R1: 2k7; R-10
R2, R3, R4: 10k; R-10
SW1: JTP-1130
U$39: OPEN_SOURCE_HW; OPENHW

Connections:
!EXROM: C3.1, IC2.2 (O), IC2.4 (O), IC2.6 (O), IC2.8 (O), J1.9 (!EXROM)
!I/O1: IC2.3 (I), IC2.9 (I), J1.7 (!I/O1)
!I/O2: IC2.13 (I), J1.10 (!I/O2)
!OE: IC1.22 (!G!VPP), IC2.10 (O), IC2.12 (O), R1.1
!RESET: IC2.1 (I), J1.C (!RESET), SW1.1, SW1.2
!ROML: IC2.5 (I), IC2.11 (I), J1.11 (!ROML)
+5V: C1.2, C2.2, IC1.28 (VCC), IC2.14 (VCC), J1.2 (+5V), J1.3 (+5V), R1.2, R2.2, R3.2, R4.2
A0: IC1.10 (A0), J1.Y (A0)
A1: IC1.9 (A1), J1.X (A1)
A2: IC1.8 (A2), J1.W (A2)
A3: IC1.7 (A3), J1.V (A3)
A4: IC1.6 (A4), J1.U (A4)
A5: IC1.5 (A5), J1.T (A5)
A6: IC1.4 (A6), J1.S (A6)
A7: IC1.3 (A7), J1.R (A7)
A8: IC1.25 (A8), J1.P (A8)
A9: IC1.24 (A9), J1.N (A9)
A10: IC1.21 (A10), J1.M (A10)
A11: IC1.23 (A11), J1.L (A11)
A12: IC1.2 (A12), J1.K (A12)
A13: IC1.26 (A13), JP1.2, JP4.2, R4.1
A14: IC1.27 (A14), JP2.2, JP4.4, R3.1
A15: IC1.1 (A15), JP3.2, JP4.6, R2.1
D0: IC1.11 (D0), J1.21 (D0)
D1: IC1.12 (D1), J1.20 (D1)
D2: IC1.13 (D2), J1.19 (D2)
D3: IC1.15 (D3), J1.18 (D3)
D4: IC1.16 (D4), J1.17 (D4)
D5: IC1.17 (D5), J1.16 (D5)
D6: IC1.18 (D6), J1.15 (D6)
D7: IC1.19 (D7), J1.14 (D7)
GND: C1.1, C2.1, C3.2, IC1.14 (VSS), IC1.20 (!E), IC2.7 (GND), J1.1 (GND), J1.22 (GND), J1.A (GND), J1.Z (GND), JP1.1, JP2.1, JP3.1, JP4.1, JP4.3, JP4.5, SW1.3, SW1.4

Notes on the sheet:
EPYX FastLoad
Sven Petersen
146-1-01-02
Cartridge for C64

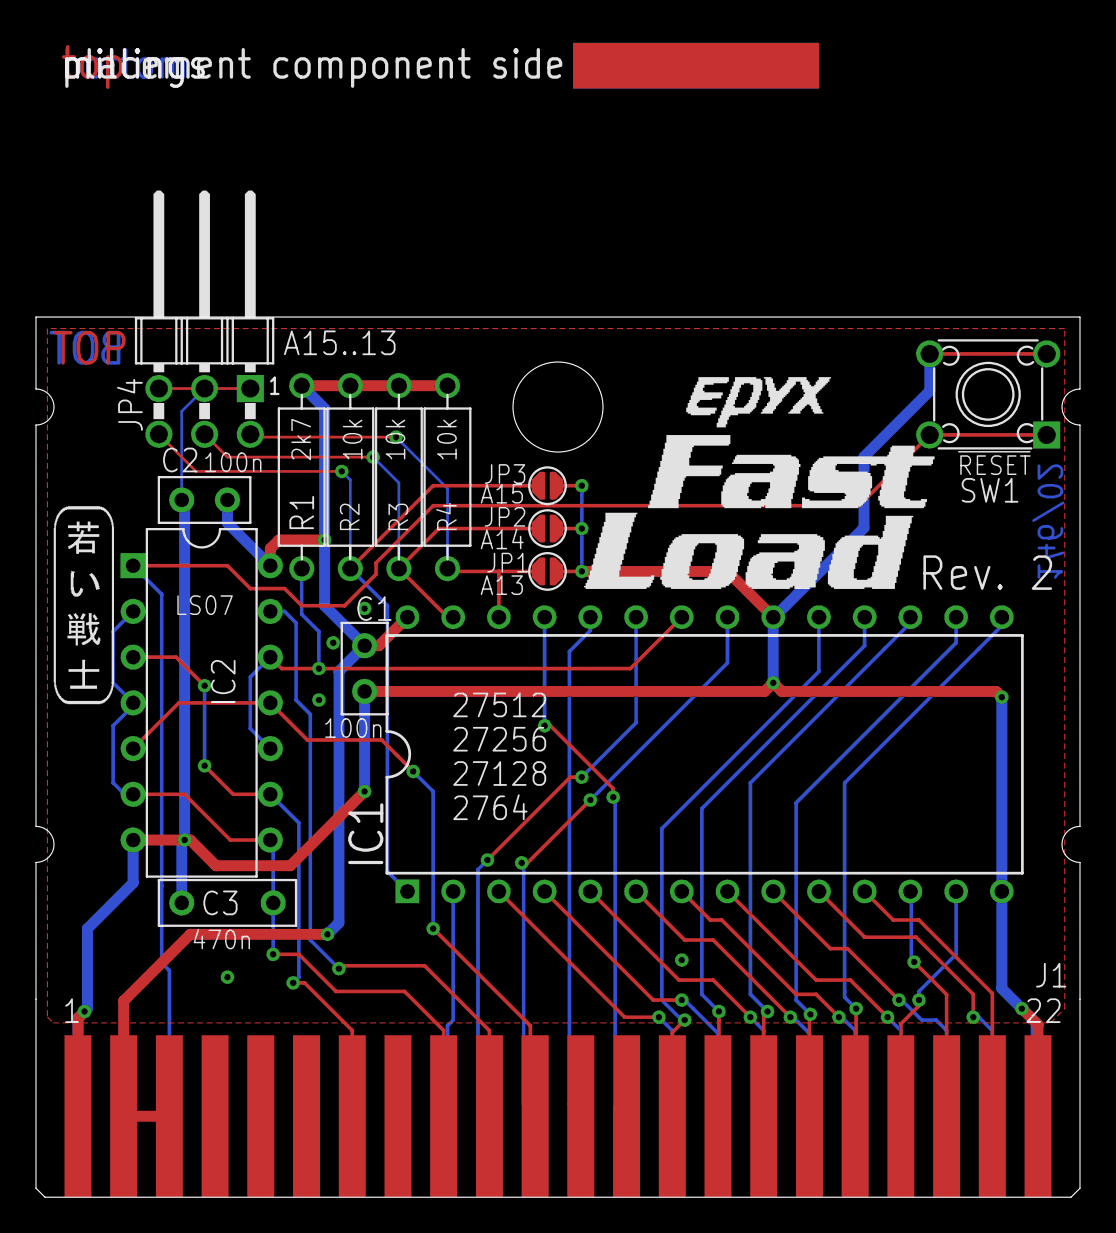
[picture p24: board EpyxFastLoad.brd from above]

Board: 2 copper layers, 58.0 x 48.9 mm, 20 parts (1 on the bottom side), 32 nets.

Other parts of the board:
U$11: EPYXFL
U$40: 2LAYER
U$41: PCB-TITLE/
U$42: SVEN_TAG

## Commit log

2020-08-08 Rev. 1 released
    [EpyxFastLoad.brd, EpyxFastLoad.sch, Epyx_FastLoad_BOM_v0_0_calc.xlsx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]
2022-10-24 Rev. 2 uploaded
    [EpyxFastLoad.brd, EpyxFastLoad.sch, EpyxFastLoad_noFrame.brd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]
